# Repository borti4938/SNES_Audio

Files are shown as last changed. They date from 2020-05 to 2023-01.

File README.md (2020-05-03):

### SNES Audio Mods
---

This is a collection of earlier projects. These projects are not under development anymore. Documentation is rather simple or simply not present

Please don't write me for any support. Please reach out to community forums and use the knowledge and experiences there.

If you want to change something on the digital audio mod, I suggest you to replace the TI-SPDIF audio encoder by CirrusLogic-SPDIF audio encoder of same size (but different pinout).

Best Regards, Peter

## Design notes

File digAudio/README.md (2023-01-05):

### IMPORTANT NOTE:

There is a bug on all PCBs manifacture before Jan 5th., 2023!
Pin 14 on the DIT4096 IC is not properly connected.
Instead of tied to GND the pin was left floating.

If you have one effected board, you can easily fix that.
Simply connect pin 14 of the DIT4096 on your PCB to GND.
This pin is a corner pin and you can use any GND pad.
This should be an easy fix.

Sorry for any inconvenience caused! 

-----------------------------------------------------------------------------------

### Solder Joints:

A mapping Pads of PCB to S-DSP/S-APU is given on the bottoms silkscreen.  
Take a picture of it if needed.

-----------------------------------------------------------------------------------

### Components:

See BOM.xlsx (use the appropriate page)  

-----------------------------------------------------------------------------------

### RCA or XLR setup

Design supports both setups. Please be refered to the notes of left in the BOM

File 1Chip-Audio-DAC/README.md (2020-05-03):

SNES 1Chip Audio DAC replacement
--------------------------------

### Purpose

This board design is suited to replace the 1Chip-SNES audio DAC, which is labeled by U6.  
This board **does not** fixes dead S-MIX, which is U10.

At the moment I don't know whether the boards fits (mechanically) into a SNES model 2 (small form factor SNES)

### Installation

- assemble the board (BOM on bottom silk screen and listed below)
- remove U6
- if you are going to recap your system, you can remove C15 and leave the footprint of C15 unpopulated  
  (it does not hurt to left C15 in place)
- connect the board to the footprint of U6. Check up for adjacent shorts afterwards.  
  (the board do not have to be isolated from bottom as it's a single layer design)
- check for connections at U6:
  - p1: R48 (bottom side mainboard) (audio out right)
  - p2: C15 + (and Vcc through board design)
  - p3: GND
  - p4: R51 (bottom side of mainboard) (audio out left)
  - p5: U2 pin 94 (LRCK)
  - p6: U2 pin 93 (DATA)
  - p7: U2 pin 92 (SCLK)
  - p8: Vcc (+5V)
- connect pad labeld by _U2:52_ with U2 pin 52 (also extension port pin 21)

### BOM

- U1: CS4338-KSZ (SOIC-8 package)
- C1: 0.1uF / 25V+ (SMD 0603 package)
- C2: 1uF /25V+ (SMD 0603 package)

### PCB

Get your PCB from OSHPark or anywhere you like.  
To smoothen the installation, choose a substrate thickness as thin as possible.

## ENJOY!!!

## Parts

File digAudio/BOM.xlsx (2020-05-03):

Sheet: OC0808
Designator | MPN | QTY | DESCRIPTION | VALUE | PACKAGE | NOTES
U1 | DIT4096IPW | 1 | 96kHz Audio Transmitter |  | TSSOP-28
JT OC0808 | FCR684208T | 1 | Toslink Transmitter |  | OTJ-8 | Designator name from former version
 |  |  |  |  |  | available at conrad.de e.g.: https://www.conrad.de/de/lwl-steckverbinder-cliff-fcr684208t-toslink-sender-606379.html
C1,C2,C3 | GRM188R71H104KA93J | 3 |  | 0.1uF / 50V | SMD 0603
Spacer / standoff | use M3 spacer | 1 | length between 7mm and 8mm |  |  | depending on your cutout
Washer |  | x |  |  |  | use washer to adjust standoff and srew fit
Screws |  | 2
MPNs are only suggestions! You can use equivalent components, too.

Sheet: PLT133
Designator | MPN | QTY | DESCRIPTION | VALUE | PACKAGE | NOTES
U1 | DIT4096IPW | 1 | 96kHz Audio Transmitter |  | TSSOP-28
PLT133/T10W | PLT133/T10W | 1 | Toslink Transmitter
C1,C2,C3 | GRM188R71H104KA93J | 3 |  | 0.1uF / 50V | SMD 0603
Spacer / standoff | use M3 spacer | 1 | length between 7mm and 8mm |  |  | depending on your cutout
Washer |  | x |  |  |  | use washer to adjust standoff and srew fit
Screws |  | 2
MPNs are only suggestions! You can use equivalent components, too.

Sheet: RCJ-DA101JC
Designator | MPN | QTY | DESCRIPTION | VALUE | PACKAGE | NOTES
U1 | DIT4096IPW | 1 | 96kHz Audio Transmitter |  | TSSOP-28
C1,C2 | GRM188R71H104KA93J | 2 |  | 0.1uF / 50V | SMD 0603
DA101JC | DA101JC | 1 | Audio transformer |  | SMD-6
For RCA-Setup
RCJ-01x-SMT | RCJ-013-SMT-TR | 1 | RCA connector 9.0mm / 3.2mm |  |  | needs to be trimmed due to PCB thickness to fit nicely
 |  |  |  |  |  | x = color of isolating material
C3 | GRM188R70J103KA01D | 1 |  | 10nF / 50V | SMD0603
R1 | CRCW0603348RFKEA | 1 |  | 347.5ohm / 0.1W | SMD0603
R2 | CRCW060391R0FKEA | 1 |  | 90.9ohm / 0.1W | SMD0603
J1 |  |  |  |  |  | close jumper at upper branch (marked half)
For XLR setup | (untested)
C3 | GRM188R71H104KA93J | 1 |  | 0.1uF / 50V | SMD0603
R1 | CRCW060357R6FKEA | 1 |  | 57ohm /0.1W
R2 |  |  |  |  |  | leave R2 unpopulated
J1 |  |  |  |  |  | close jumper at lower half
XLR | positive |  |  |  |  | connect positive part to middle pad of RCJ-01x-SMT footprint
 | negative |  |  |  |  | connect positive part to left or right pad of RCJ-01x-SMT footprint
MPNs are only suggestions! You can use equivalent components, too.

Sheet: RCJ-tg10da1nslf
Designator | MPN | QTY | DESCRIPTION | VALUE | PACKAGE | NOTES
U1 | DIT4096IPW | 1 | 96kHz Audio Transmitter |  | TSSOP-28
C1,C2 | GRM188R71H104KA93J | 2 |  | 0.1uF / 50V | SMD 0603
TG10-DA1NSLF | TG10-DA1NSLF | 1 | Audio transformer |  | SMD-6
For RCA-Setup
RCJ-01x-SMT | RCJ-013-SMT-TR | 1 | RCA connector 9.0mm / 3.2mm |  |  | needs to be trimmed due to PCB thickness to fit nicely
 |  |  |  |  |  | x = color of isolating material
C3 | GRM188R70J103KA01D | 1 |  | 10nF / 50V | SMD0603
R1 | CRCW0603348RFKEA | 1 |  | 347.5ohm / 0.1W | SMD0603
R2 | CRCW060391R0FKEA | 1 |  | 90.9ohm / 0.1W | SMD0603
J1 |  |  |  |  |  | close jumper at upper branch (marked half)
For XLR setup | (untested)
C3 | GRM188R71H104KA93J | 1 |  | 0.1uF / 50V | SMD0603
R1 | CRCW060357R6FKEA | 1 |  | 57ohm /0.1W
R2 |  |  |  |  |  | leave R2 unpopulated
J1 |  |  |  |  |  | close jumper at lower half
XLR | positive |  |  |  |  | connect positive part to middle pad of RCJ-01x-SMT footprint
 | negative |  |  |  |  | connect positive part to left or right pad of RCJ-01x-SMT footprint
MPNs are only suggestions! You can use equivalent components, too.

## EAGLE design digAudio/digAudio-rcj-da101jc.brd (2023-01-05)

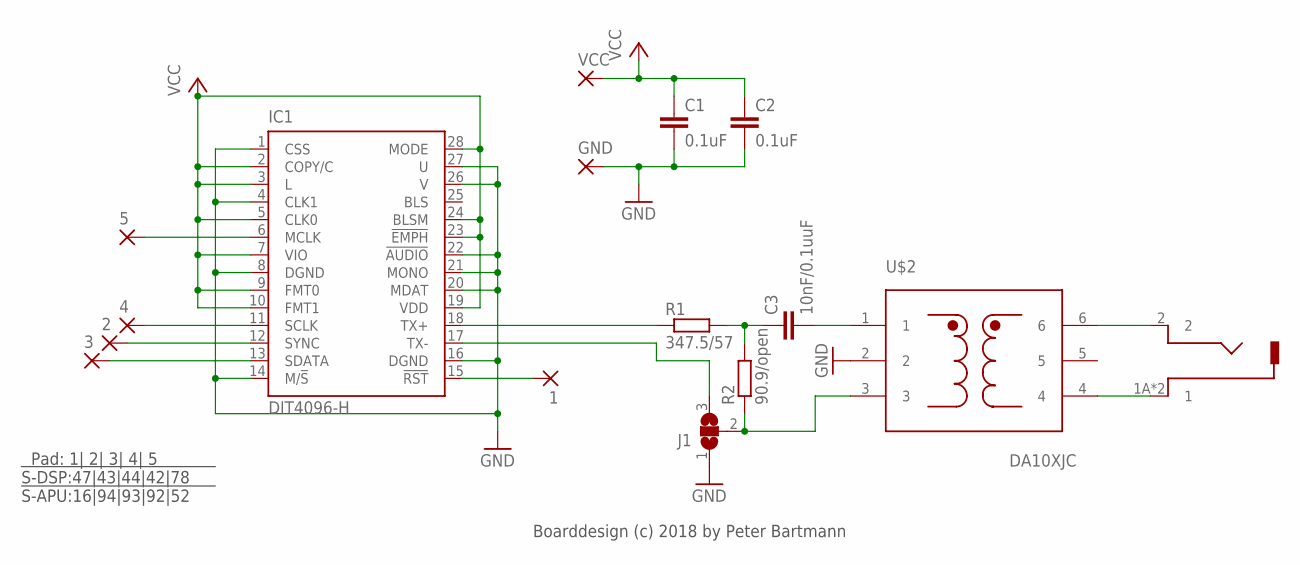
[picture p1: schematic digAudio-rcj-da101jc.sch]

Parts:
1, 2, 3, 4, 5: SMD1; SMD0,8-1,6
C1, C2: 0.1uF; C0603
C3: 10nF/0.1uuF; C0603
GND: 1,6/0,9
IC1: DIT4096-H; PW_R-PDSO-G28
J1: SJ2W; SJ_2
R1: 347.5/57; R0603
R2: 90.9/open; R0603
U$1: RCJ-013-SMT-TR; RCJ_01X_SMT_MODIFIED
U$2: DA10XJC; DA101JC
VCC: 1,6/0,9

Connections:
GND: C1.2, C2.2, GND.1, IC1.1 (CSS), IC1.4 (CLK1), IC1.8 (DGND), IC1.14 (M/!S), IC1.16 (DGND), IC1.20 (MDAT), IC1.21 (MONO), IC1.22 (!AUDIO), IC1.26 (V), IC1.27 (U), J1.1, U$2.2
unnamed: IC1.18 (TX+), R1.1
unnamed: 1.P$1, IC1.15 (!RST)
unnamed: 2.P$1, IC1.12 (SYNC)
unnamed: 4.P$1, IC1.11 (SCLK)
unnamed: 3.P$1, IC1.13 (SDATA)
unnamed: 5.P$1, IC1.6 (MCLK)
unnamed: IC1.17 (TX-), J1.3
unnamed: C3.1, R1.2, R2.2
unnamed: U$1.2, U$2.6
unnamed: U$1.1A (1), U$1.1B (1), U$2.4
unnamed: C3.2, U$2.1
unnamed: J1.2, R2.1, U$2.3
VCC: C1.1, C2.1, IC1.2 (COPY/C), IC1.3 (L), IC1.5 (CLK0), IC1.7 (VIO), IC1.9 (FMT0), IC1.10 (FMT1), IC1.19 (VDD), IC1.23 (!EMPH), IC1.24 (BLSM), IC1.28 (MODE), VCC.1

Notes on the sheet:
Pad: 1| 2| 3| 4| 5 S-DSP:47|43|44|42|78 S-APU:16|94|93|92|52
Boarddesign (c) 2018 by Peter Bartmann

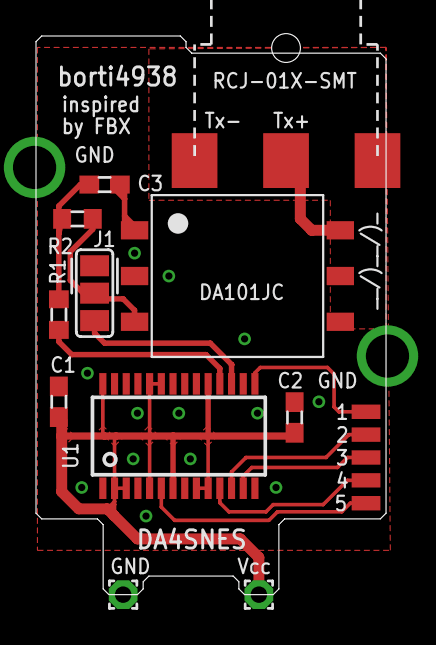
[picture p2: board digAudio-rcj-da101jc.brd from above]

Board: 2 copper layers, 19.4 x 31.0 mm, 16 parts (0 on the bottom side), 14 nets.

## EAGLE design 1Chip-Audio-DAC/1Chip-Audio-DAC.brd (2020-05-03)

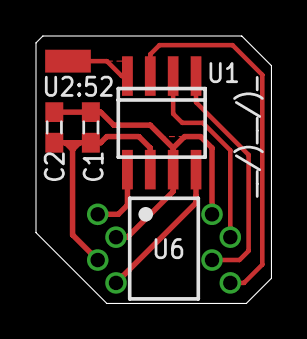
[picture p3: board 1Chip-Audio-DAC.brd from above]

Board: 2 copper layers, 13.1 x 14.9 mm, 4 parts (0 on the bottom side), 3 nets.

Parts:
C1: 0.1u; C0603
C2: 1u; C0603
MCLK: SMD1,27-2,54
U1: CS4338-KSZ; SO-08

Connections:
AGND: C1.1, C2.1, U1.6
MCLK: MCLK.1, U1.4
VA: C1.2, C2.2, U1.7

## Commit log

2020-05-03 initial commit for archive
    [1Chip-Audio-DAC.brd, BOM.xlsx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]
2023-01-05 bugfix on PCBs: - pin 14 (M/nS) was floating - now it is properly connected to GND
    [digAudio-OC0808.GBL, digAudio-OC0808.GBO, digAudio-OC0808.GBS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]

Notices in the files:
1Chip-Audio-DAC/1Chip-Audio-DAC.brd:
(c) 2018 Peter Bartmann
